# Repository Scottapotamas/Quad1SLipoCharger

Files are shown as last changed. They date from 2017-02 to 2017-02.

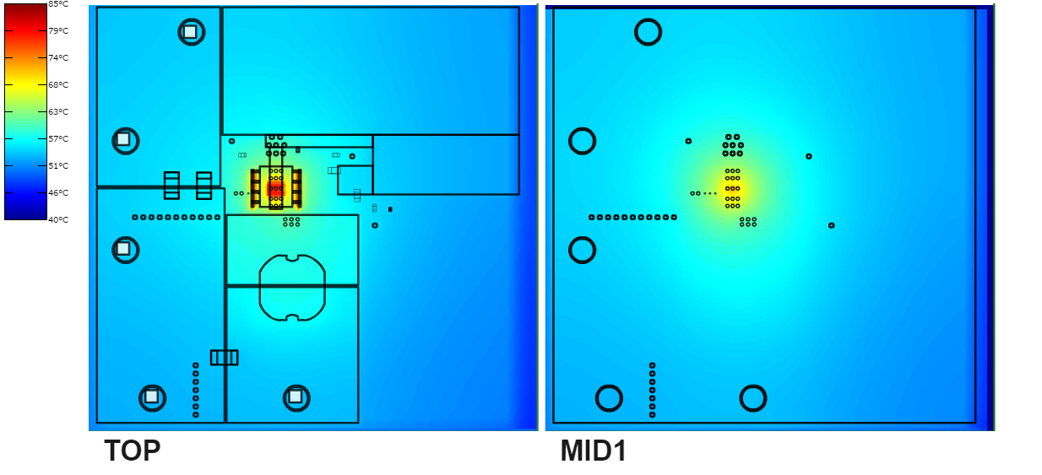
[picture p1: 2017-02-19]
Regulator Notes/Thermal 1.PNG

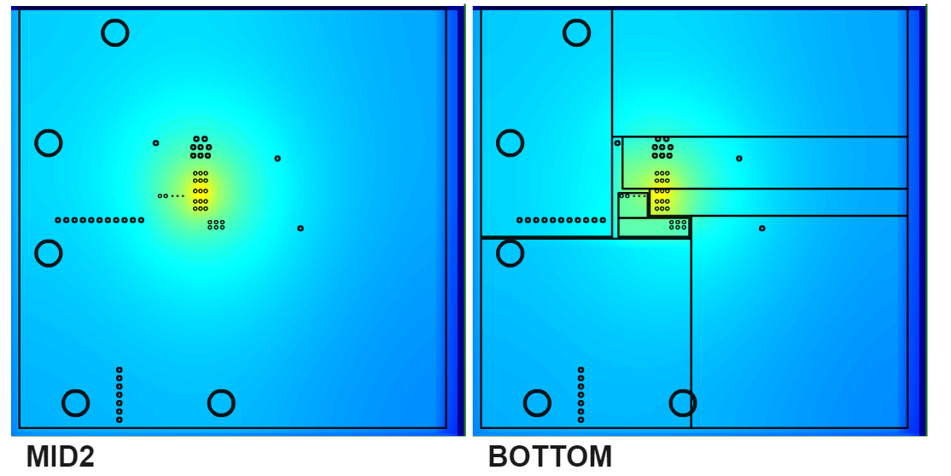
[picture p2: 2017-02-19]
Regulator Notes/Thermal 2.PNG

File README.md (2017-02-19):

# Quad1SLipoCharger
Charges up to 4 1S lipo batteries, independantly. Settable 300, 500 or 800mA charge current per battery.

# Version 2.0
Version 2.0 was the first variant that uses the STC08 IC for charging, as it offers better performance and programmable current limits which the older MAX charging IC didn't on V1.

A few of these V2 boards were made as a test, and performed very well charging 4 batteries in the field for micro brushed quads. 

The biggest issue has been the physical connectors to the batteries, given the multitude of competing battery connectors used on brushed aircraft. V2.0 used JST-PH and then adaptor cables I made up, but this doesn't suit the fully range as easily as hoped.

That said, two of these prototype boards have charged over 100 batteries with no issues, and charging/regulation seems safe, stable and reliable.

# Version 2.1

Having tested V2 in person some changes were made which are represented in V2.1, mainly increased thermal considerations, removal of some status leds, and simplification of the layout. 

Connectors were changed to be compatible with the smaller 1S batteries found on TinyWhoop/RTF planes, and rotated to allow for direct connections to the board.

The board was also shrunk, and the XT60 footprint corrected based on discoveries relating to incorrect datasheets used for V2.0 footprint design.

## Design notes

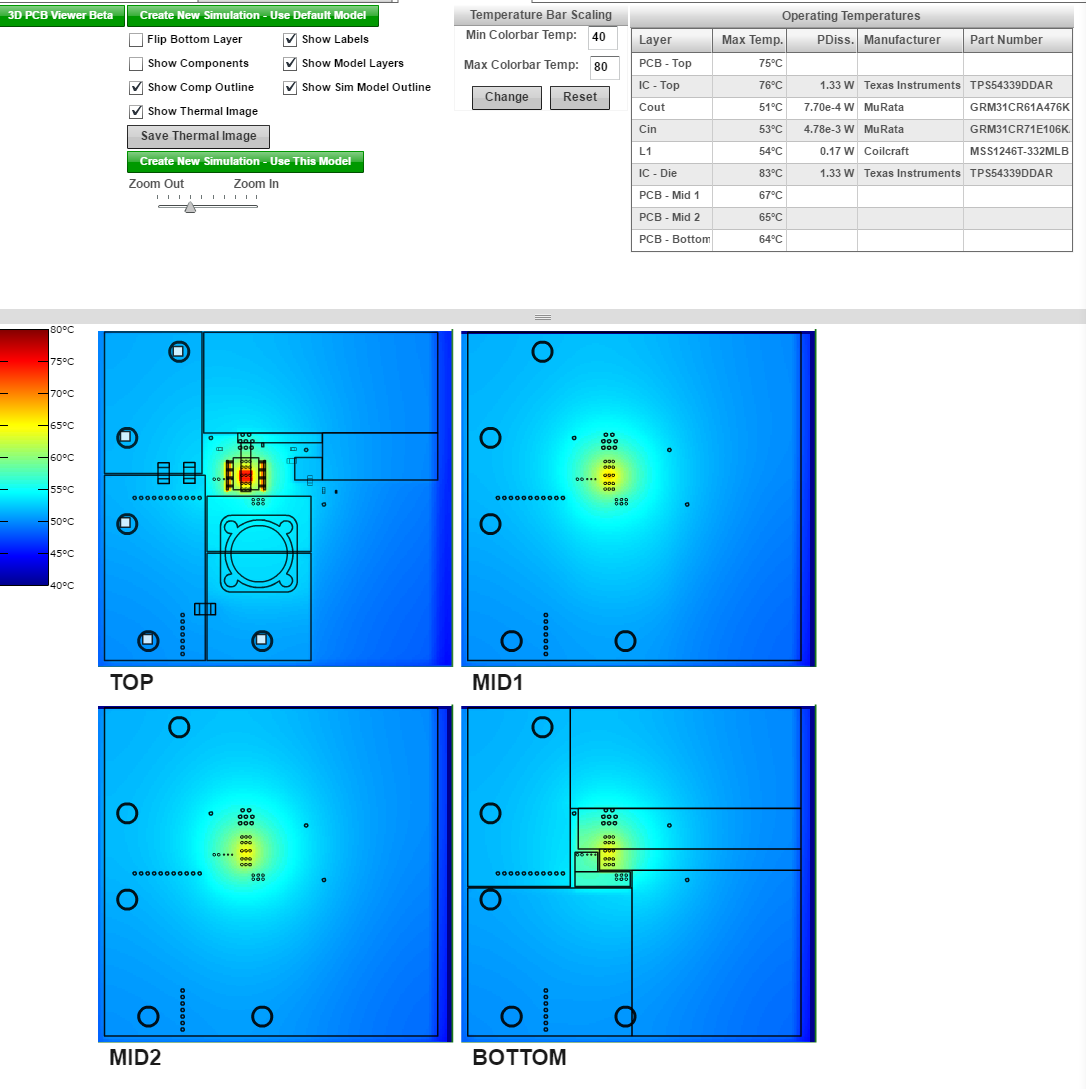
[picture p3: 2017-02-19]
Regulator Notes/Thermal 3S .PNG

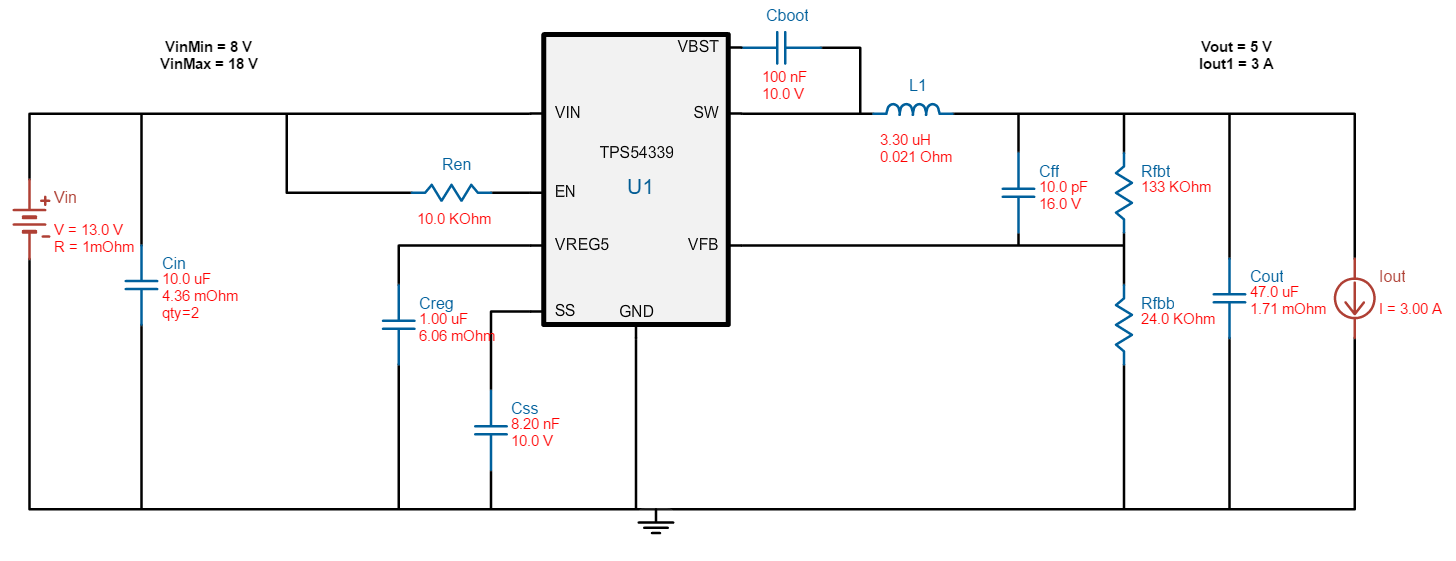
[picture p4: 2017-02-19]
Regulator Notes/PSU Circuit.PNG

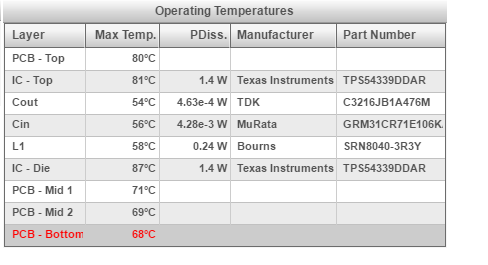
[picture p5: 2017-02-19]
Regulator Notes/Thermal Vals.PNG

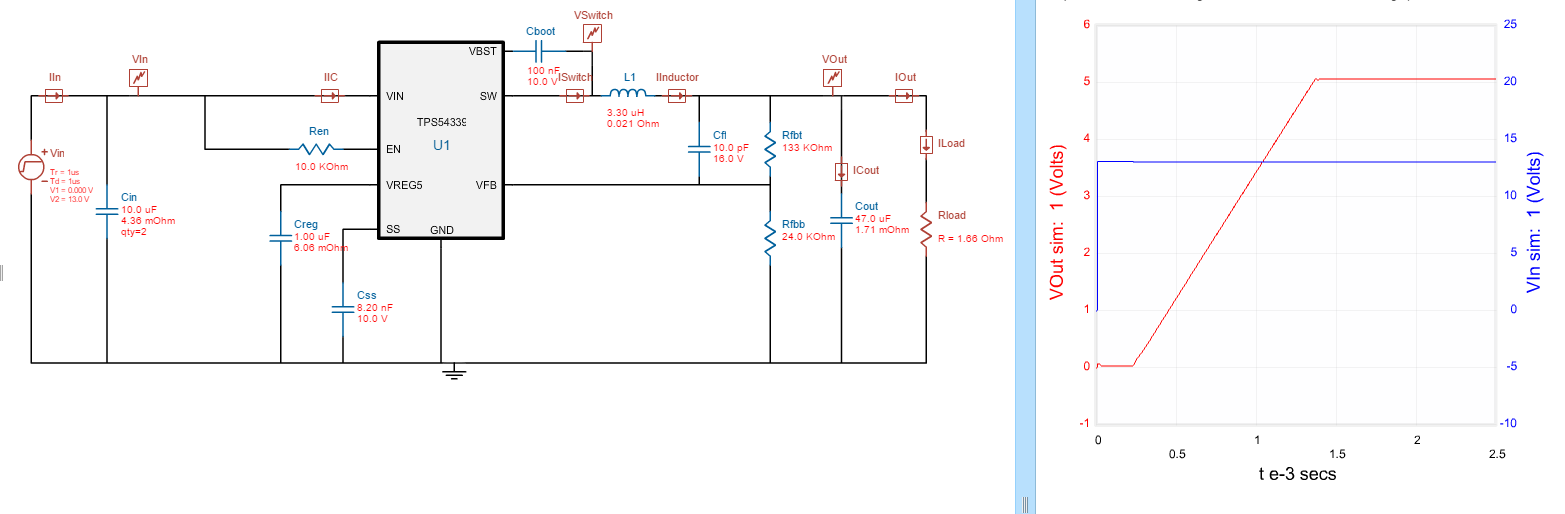
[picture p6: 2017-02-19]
Regulator Notes/PSU Sim.PNG

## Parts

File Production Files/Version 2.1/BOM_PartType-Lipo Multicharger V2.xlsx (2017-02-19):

Comment | Designator | Description | LibRef | Quantity | Note | Example
XT60PT |  | Amass PCB Mount XT60 Connector | CMP-ys0k18bgy9431xxyemrn-2 | 1 | If can't source easily I will solder myself | https://www.aliexpress.com/item/1-5-10-20-Pairs-Amass-XT60PT-3-5mm-Banana-Connector-Plug-Male-Female-Gold-plated/32706595068.html
Molex 53047-0210 | B1, B2, B3, B4 | 1.25mm Pitch PicoBlade™ Wire-to-Board Header, Vertical, 2 Circuits. | CMP-5075997b4c378fb2-1 | 4 | DO NOT PLACE, INCLUDE IN BAG
0603 100nF | C1 | AVX 0603 100nF 0603YC104K4Z2A | CMP-955451-2 | 1
0603 10pF | C2 | Multilayer Ceramic Capacitors MLCC - SMD/SMT 50volts 10pF 5% C0G | CMP-3554890-2 | 1
1210 10uF | C3, C4 | CAP CER 10UF 25V 10% X5R 1210 | CMP-127194-2 | 2
0603 1uF | C5, C8 | CAP CER 1UF 10V Y5V 0603 | CMP-126001-2 | 2
0603 10nF | C6 | CAP CER 10000PF 25V 10% X7R 0603 | CMP-171279-2 | 1
1210 47uF | C7, C17 | 1210 47 uF 10 V ±10% Tolerance X5R SMT Multilayer Ceramic Capacitor | CMP-cdd204dbeb8b1215-2 | 2
0603 4.7uF X5R | C9, C10, C11, C12, C13, C14, C15, C16 | Cap Ceramic 4.7uF 10V X5R 10% SMD 0603 85C | CMP-9133140-3 | 8
SMB 3A 40V | D1 | DIODE SCHOTTKY 100V 3A SMB | CMP-816754-2 | 1
SMAJ30CAHE3/5A | D2 | Transient Voltage Suppressor, 6.40 to 231 V, 30 V Stand-off Voltage, Bi-Directional, -55 to 155 degC, 2-pin DO-214AC | CMP-16576639-3 | 1 |  | https://www.aliexpress.com/item/Free-Shipping-Electronics-SMAJ30CAHE3-5A-TVS-BIDIR-400W-30V-5-SMA-SMAJ30CAHE3-SMAJ30-30C-20pcs/32433853051.html
0603 Red | POWER | Red 1.6 x 0.8 x 0.8 mm 130° Water Clear 10 mcd 2.1 V SMT LED | CMP-1544853-3 | 1
0603 Green | D4, D6, D8, D10 | Green 1.6 x 0.8 x 0.8 mm 130° Water Clear 6 mcd 2.1 V SMT LED | CMP-1544853-3 | 5
IHLP2525EZER3R3M01 | L1 | Surface Mount Power Inductor, IHLP-2525EZ-01 Series, 3.3 H, 20%, Shielded, 0.0209 ohm, 8 A | CMP-55fd9e7d09658a3a-1 | 1 |  | https://www.aliexpress.com/item/Free-shipping-5pcs-lot-IHLP2525CZER3R3M01-IHLP2525-SMD-original-Product/32518321538.html
0603 10k | R1 | RES SMD 10K OHM 0.1% 1/10W 0603 | CMP-1863099-2 | 1
0603 133k 1% | R3 | Thick Film Resistors - SMD 0603 133Kohms 1% Tol | CMP-3663980-2 | 1
0603 24k 1% | R4 | Thick Film Resistors - SMD 0603 24Kohms 5% Tol | CMP-3679912-2 | 1
0603 1k | R5, R5, R7, R17, R19 | 0603 Panasonic ERJ3EKF1001V 1kOhm, 5% Tol | CMP-3654795-5 | 5
0R 0402 | R9, R11, R21, R23 | Bridge resistor 0ohm 0402 Labelled on board as 0.5 | CMP-15792799-5 | 4
Bridge 0402 | R9, R10, R11, R12, R21, R22, R23, R24 | Bridge resistor 0ohm 0402 labelled on board as 0.3. | CMP-15792799-5 | DNP | DO NOT PLACE
0603 2k | R13, R15, R25, R27 | RES SMD 2K OHM 5% 1/10W 0603 | CMP-1877180-2 | 4
0603 3.33k | R14, R16, R26, R28 | Thick Film Resistors - SMD 0603 3.3Kohms 5% Tol | CMP-3656259-2 | 4
STMicroelectronics STBC08PMR | U1, U2, U3, U4 | IC BATT CHRGR LI-ION 4.2V 800MA DFN6 | CMP-facc33d44885250b-1 | 4
Texas Instruments TPS54339DDA | U5 | 4.5V to 23V Input, 3A Synchronous Step-Down Converter with D-CAP2 Mode 8-SO PowerPAD -40 to 85 | CMP-82774aeb049e5db0-1 | 1

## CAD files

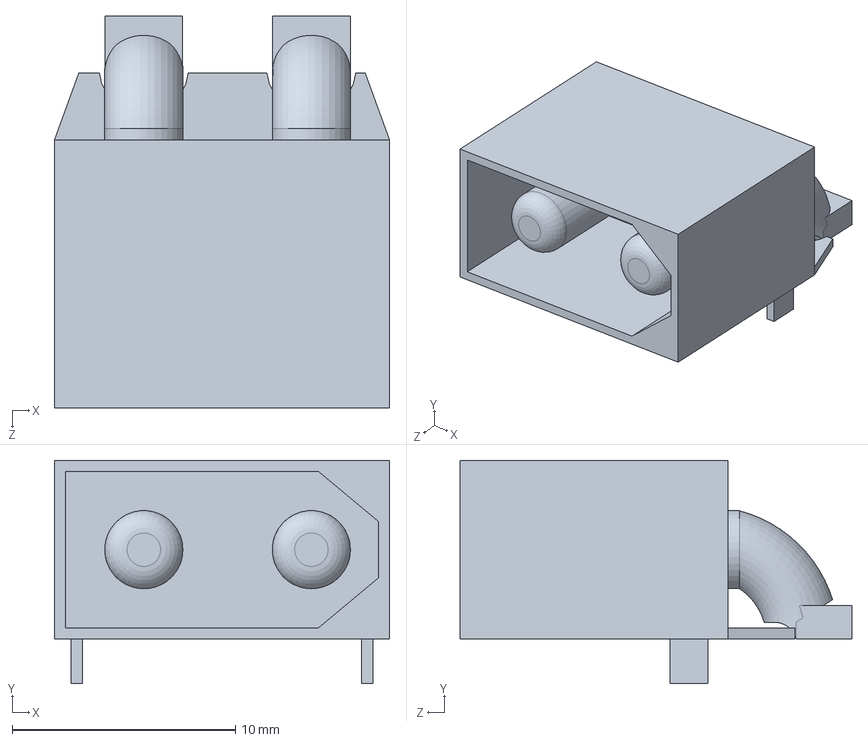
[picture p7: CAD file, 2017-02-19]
CAD/xt60pt.SLDPRT
15.0 x 10.0 x 17.5 mm

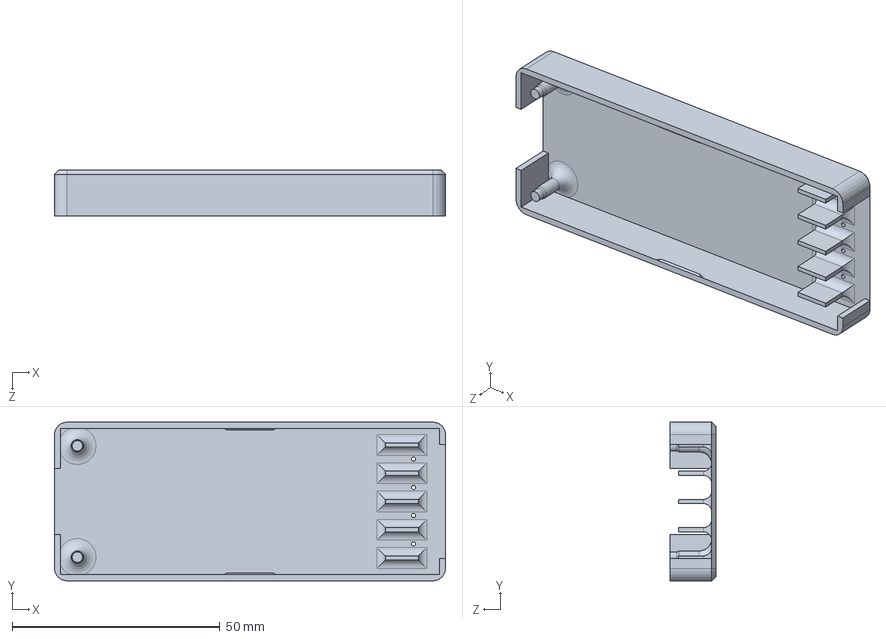
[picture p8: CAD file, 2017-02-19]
CAD/Charger housing.SLDPRT
94.1 x 38.2 x 11.0 mm

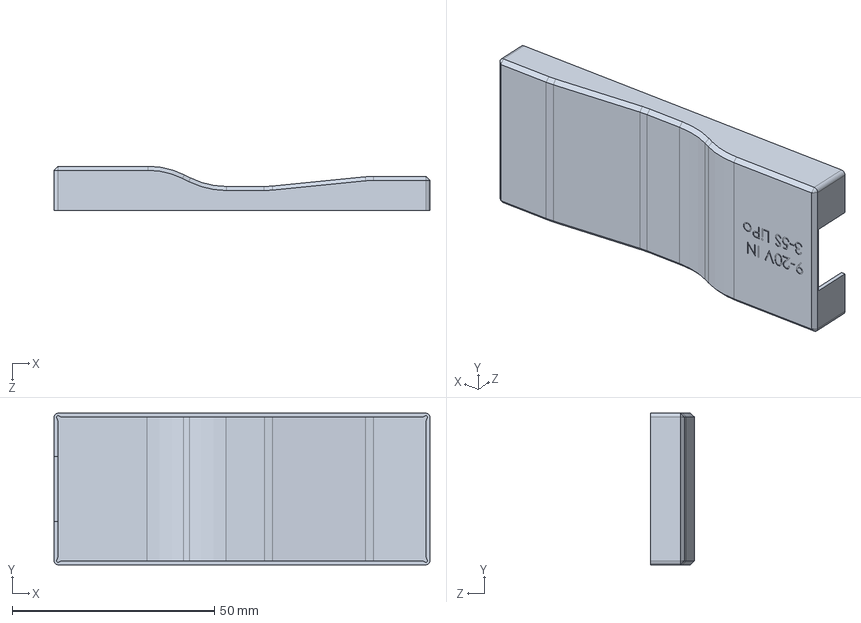
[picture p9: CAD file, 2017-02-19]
CAD/Charger housing V2.SLDPRT
93.0 x 37.5 x 11.0 mm

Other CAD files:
CAD/xt60pt v2.STEP
CAD/Charger housing V1.SLDPRT

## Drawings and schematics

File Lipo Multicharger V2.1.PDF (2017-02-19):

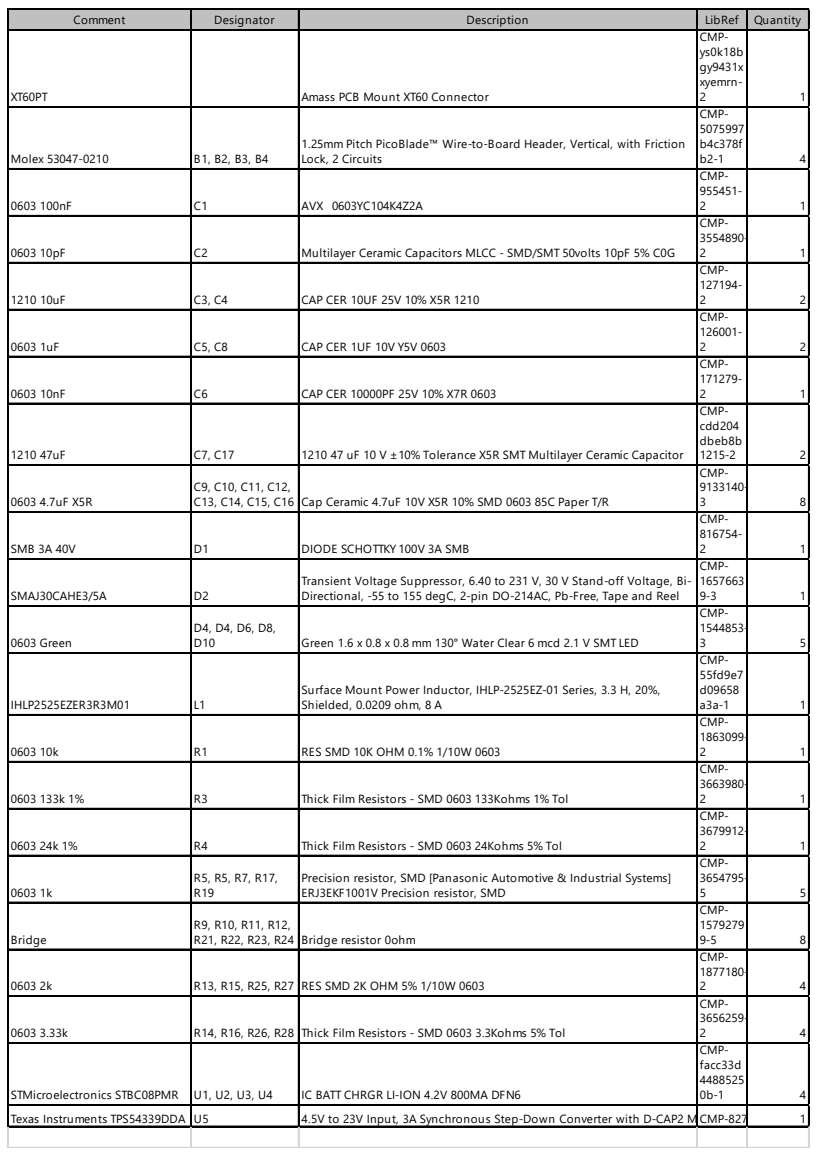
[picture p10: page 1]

Comment | Designator | Description | LibRef | Quantity

XT60PT | | Amass PCB Mount XT60 Connector | CMP-ys0k18b gy9431x xyemrn-2 | 1

Molex 53047-0210 | B1, B2, B3, B4 | 1.25mm Pitch PicoBlade™ Wire-to-Board Header, Vertical, with Friction Lock, 2 Circuits | CMP-5075997 b4c378f b2-1 | 4

0603 100nF | C1 | AVX 0603YC104K4Z2A | CMP-955451-2 | 1

0603 10pF | C2 | Multilayer Ceramic Capacitors MLCC - SMD/SMT 50volts 10pF 5% C0G | CMP-3554890-2 | 1

1210 10uF | C3, C4 | CAP CER 10UF 25V 10% X5R 1210 | CMP-127194-2 | 2

0603 1uF | C5, C8 | CAP CER 1UF 10V Y5V 0603 | CMP-126001-2 | 2

0603 10nF | C6 | CAP CER 10000PF 25V 10% X7R 0603 | CMP-171279-2 | 1

1210 47uF | C7, C17 | 1210 47 uF 10 V ±10% Tolerance X5R SMT Multilayer Ceramic Capacitor | CMP-cdd204 dbeb8b 1215-2 | 2

0603 4.7uF X5R | C9, C10, C11, C12, C13, C14, C15, C16 | Cap Ceramic 4.7uF 10V X5R 10% SMD 0603 85C Paper T/R | CMP-9133140-3 | 8

SMB 3A 40V | D1 | DIODE SCHOTTKY 100V 3A SMB | CMP-816754-2 | 1

SMAJ30CAHE3/5A | D2 | Transient Voltage Suppressor, 6.40 to 231 V, 30 V Stand-off Voltage, Bi-Directional, -55 to 155 degC, 2-pin DO-214AC, Pb-Free, Tape and Reel | CMP-1657663 9-3 | 1

0603 Green | D4, D4, D6, D8, D10 | Green 1.6 x 0.8 x 0.8 mm 130° Water Clear 6 mcd 2.1 V SMT LED | CMP-1544853-3 | 5

IHLP2525EZER3R3M01 | L1 | Surface Mount Power Inductor, IHLP-2525EZ-01 Series, 3.3 H, 20%, Shielded, 0.0209 ohm, 8 A | CMP-55fd9e7 d09658 a3a-1 | 1

0603 10k | R1 | RES SMD 10K OHM 0.1% 1/10W 0603 | CMP-1863099-2 | 1

0603 133k 1% | R3 | Thick Film Resistors - SMD 0603 133Kohms 1% Tol | CMP-3663980-2 | 1

0603 24k 1% | R4 | Thick Film Resistors - SMD 0603 24Kohms 5% Tol | CMP-3679912-2 | 1

0603 1k | R5, R5, R7, R17, R19 | Precision resistor, SMD [Panasonic Automotive & Industrial Systems] ERJ3EKF1001V Precision resistor, SMD | CMP-3654795-5 | 5

Bridge | R9, R10, R11, R12, R21, R22, R23, R24 | Bridge resistor 0ohm | CMP-1579279 9-5 | 8

0603 2k | R13, R15, R25, R27 | RES SMD 2K OHM 5% 1/10W 0603 | CMP-1877180-2 | 4

0603 3.33k | R14, R16, R26, R28 | Thick Film Resistors - SMD 0603 3.3Kohms 5% Tol | CMP-3656259-2 | 4

STMicroelectronics STBC08PMR | U1, U2, U3, U4 | IC BATT CHRGR LI-ION 4.2V 800MA DFN6 | CMP-facc33d 0b-1 | 4

Texas Instruments TPS54339DDA | U5 | 4.5V to 23V Input, 3A Synchronous Step-Down Converter with D-CAP2 MCMP -82774a | | 1

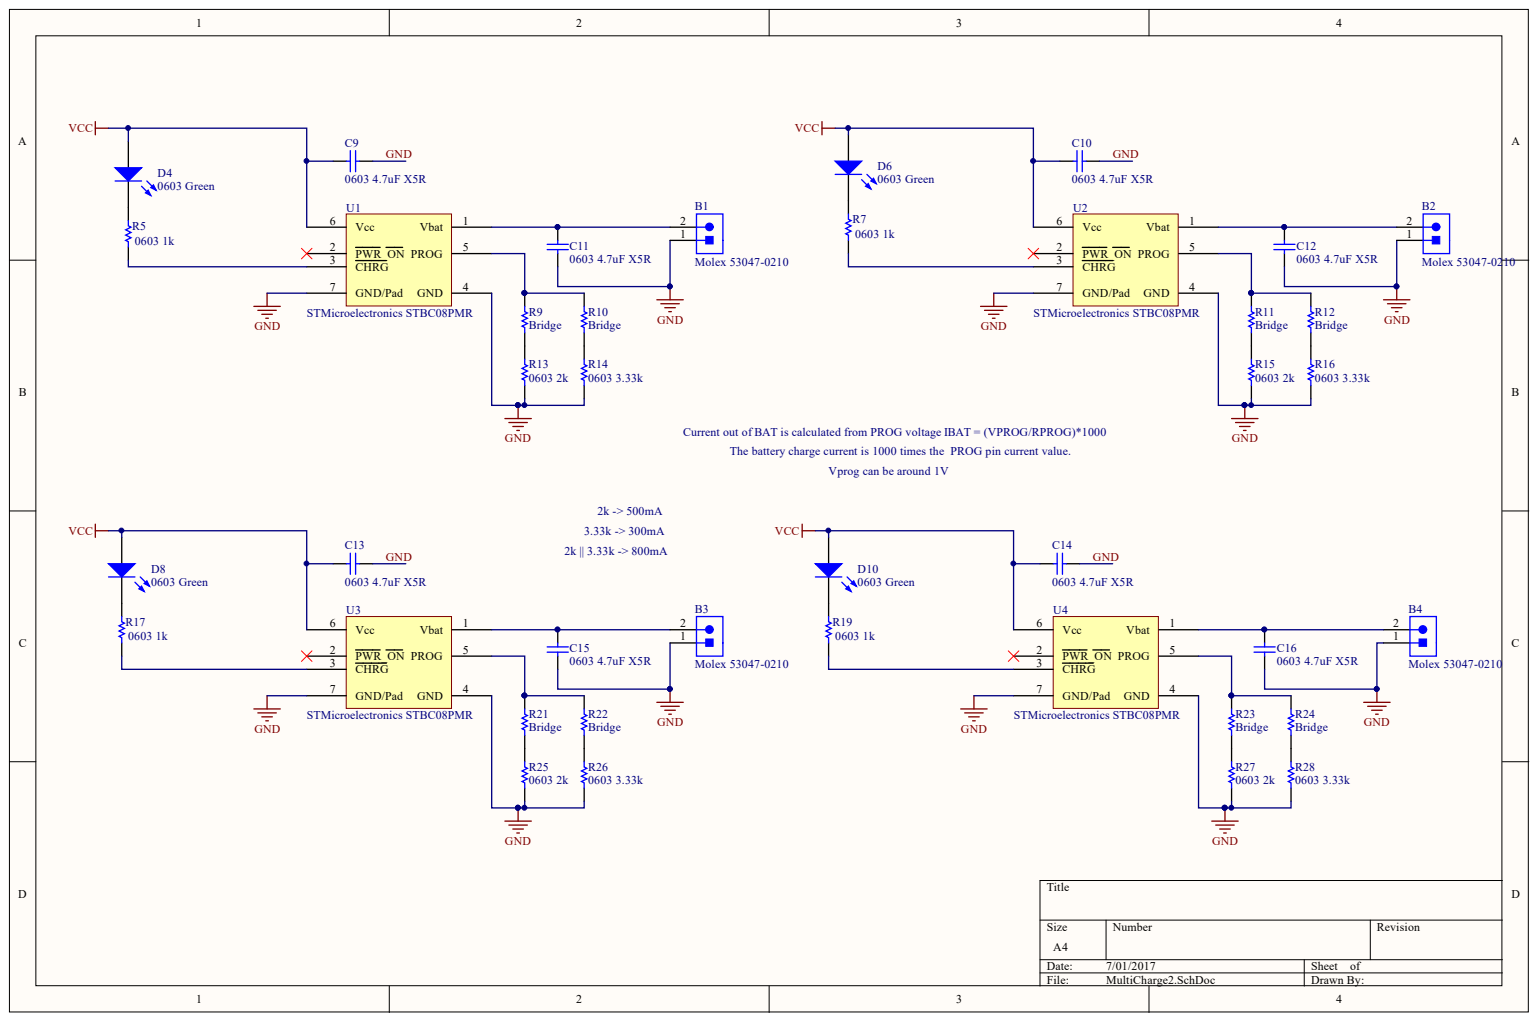
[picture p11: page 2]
Sheet o; ics STBC0; 3 Green; lex 5

D Current out of BAT is calculated from PROG voltage IBAT = (VPROG/RPROG)*1000 The battery charge current is 1000 times the PROG pin current value.

g can be aro

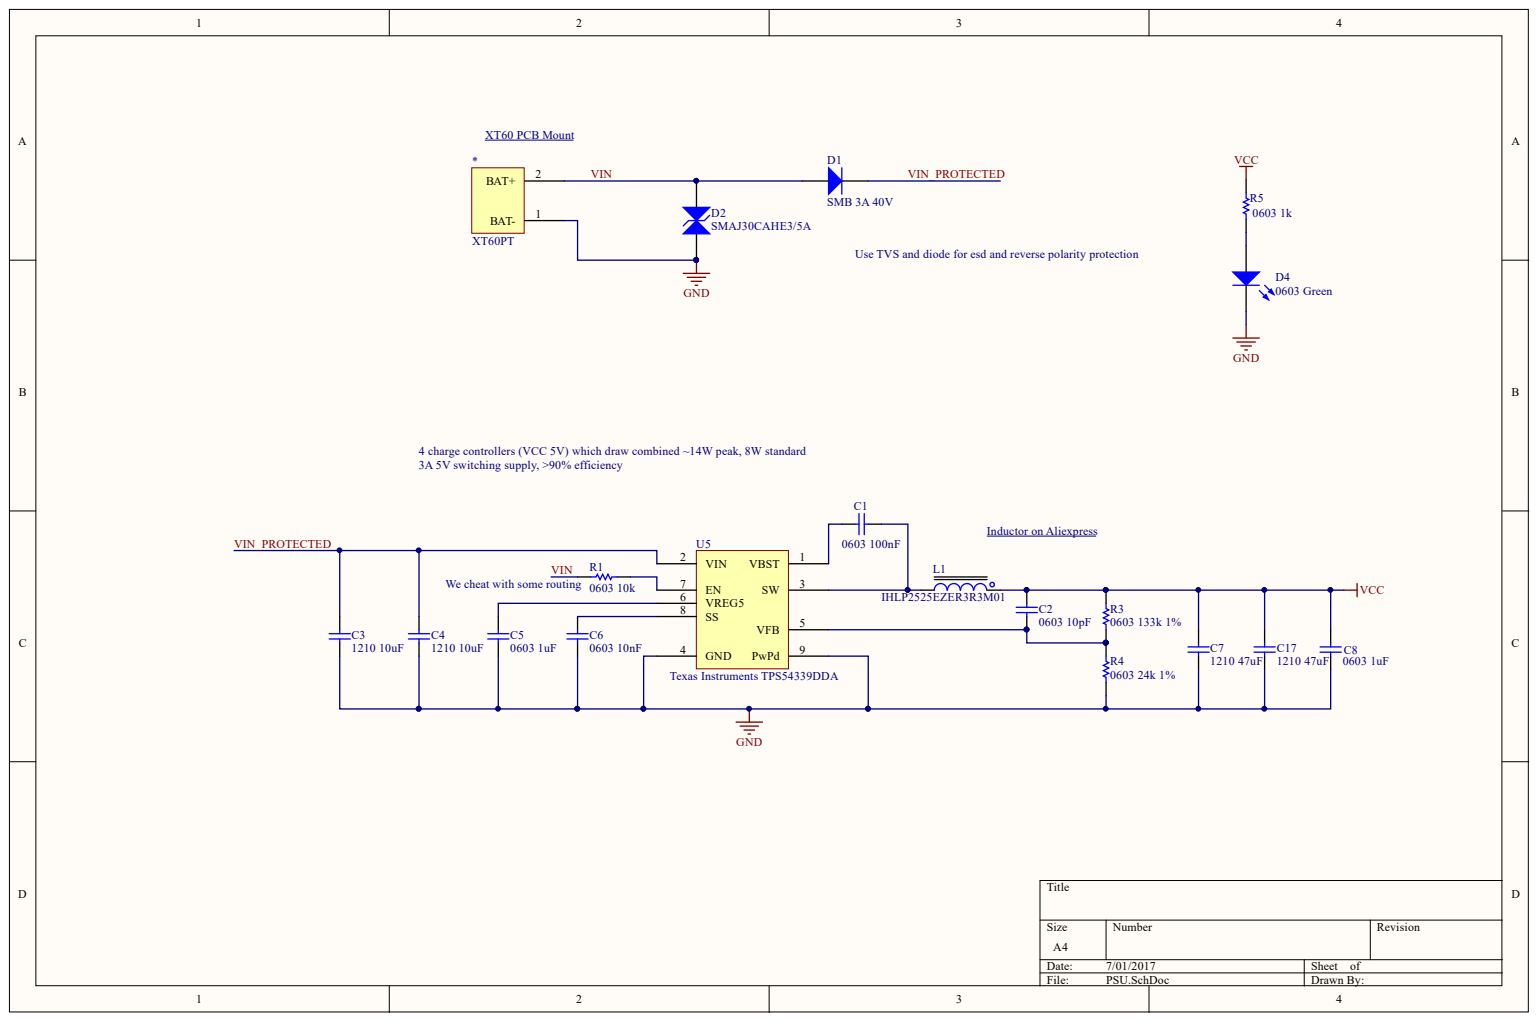
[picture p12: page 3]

Use TVS and diode for esd and reverse polarity protection

4 charge controllers (VCC 5V) which draw combined ~14W peak, 8W standard
3A 5V switching supply, >90% efficiency

We cheat with some routing

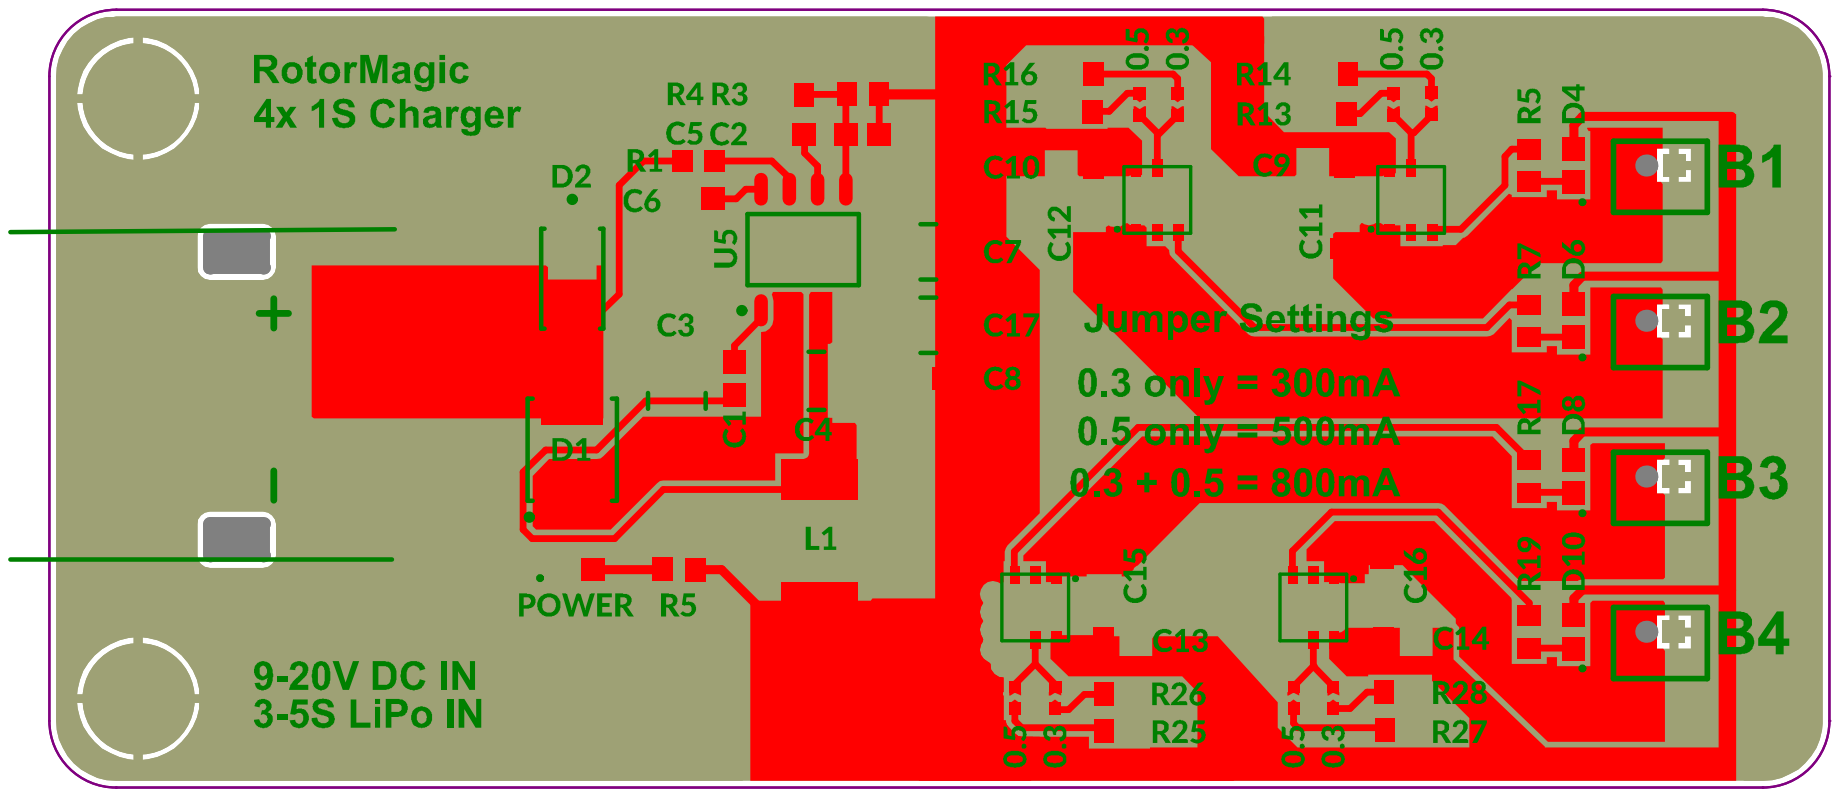
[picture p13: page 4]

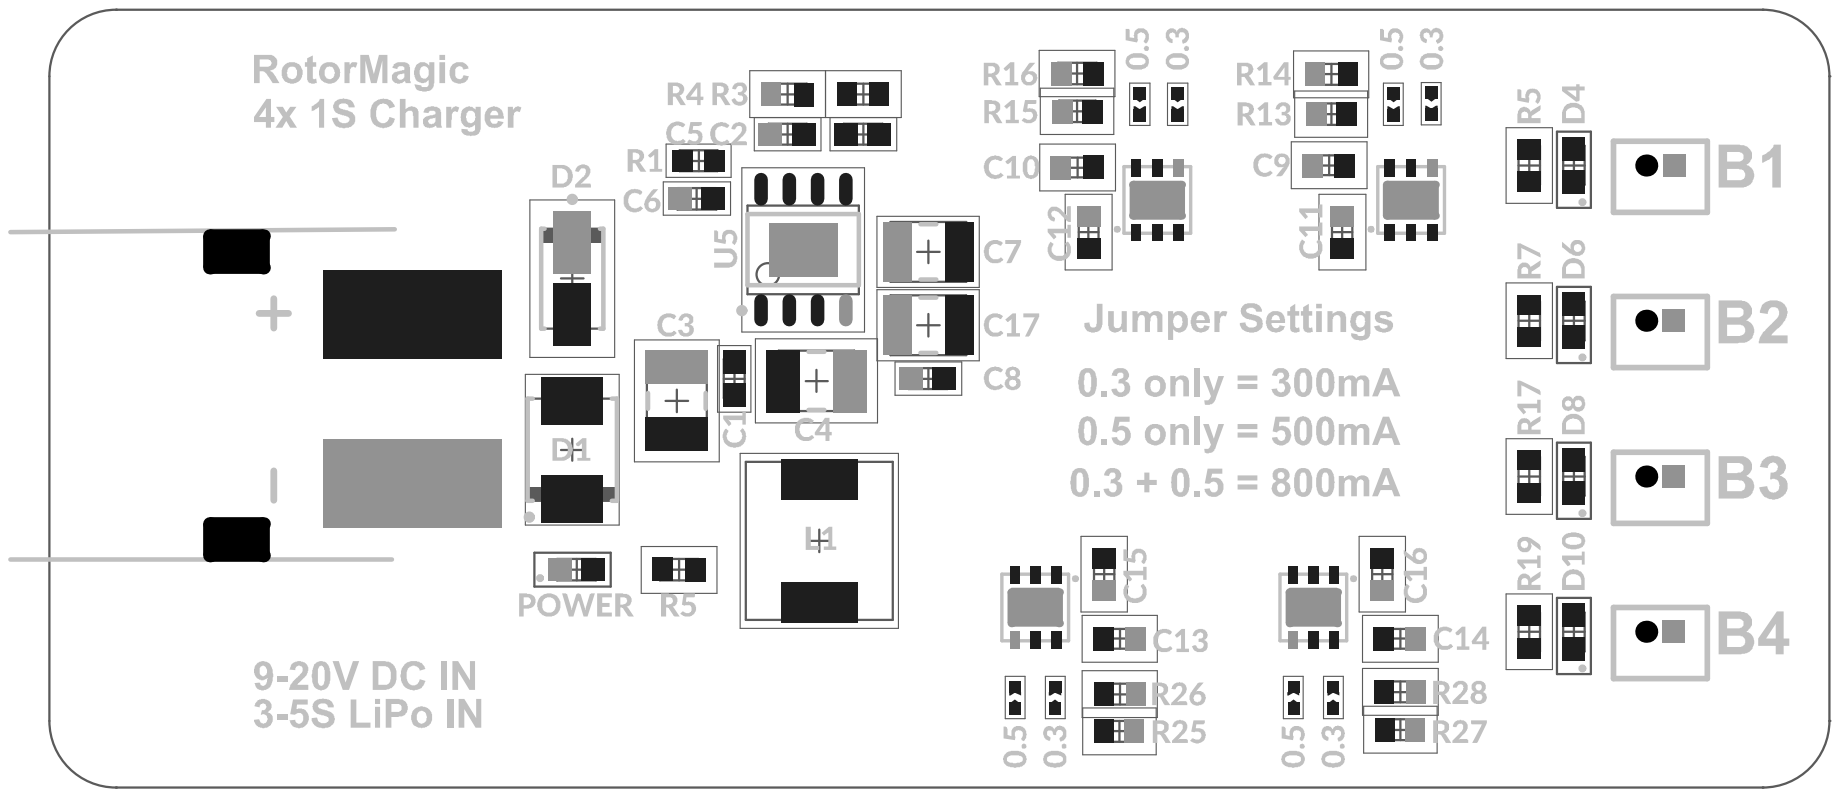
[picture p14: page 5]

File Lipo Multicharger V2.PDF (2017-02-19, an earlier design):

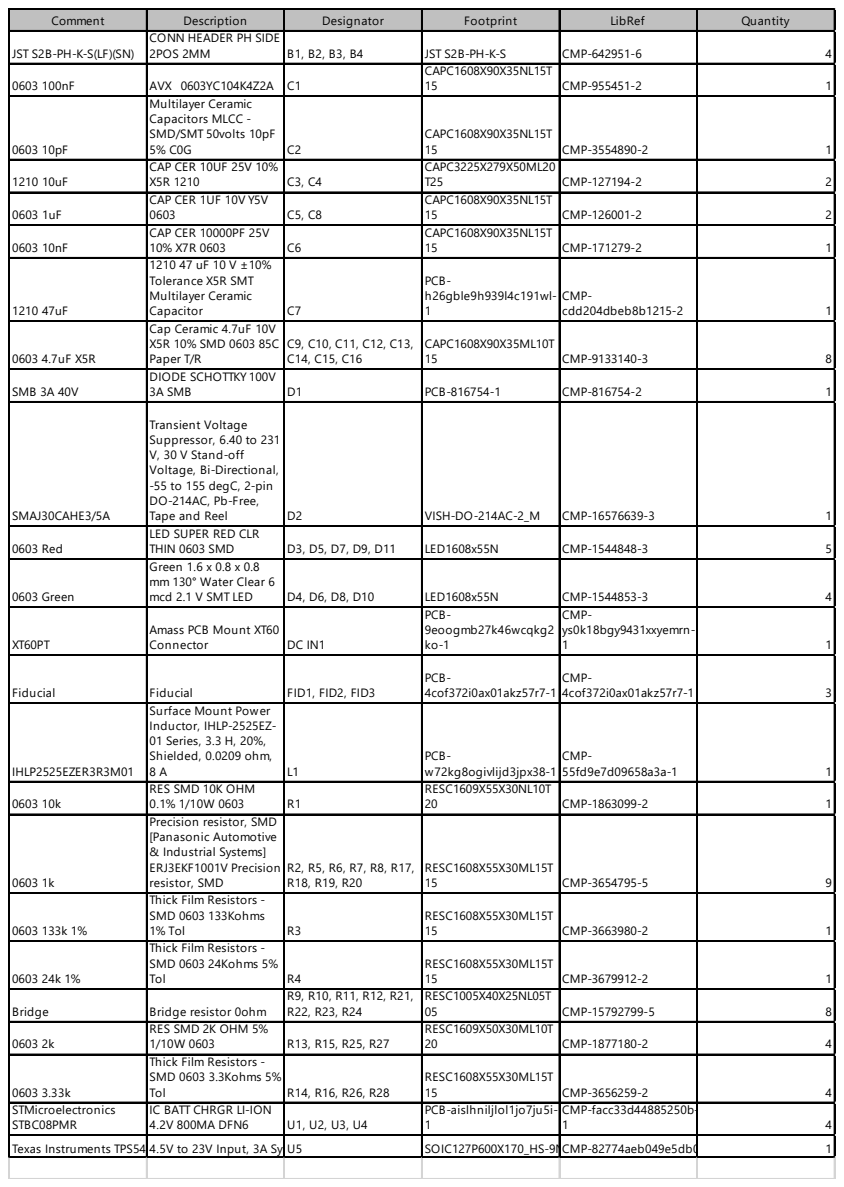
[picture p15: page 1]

Comment | Description | Designator | Footprint | LibRef | Quantity

JST S2B-PH-K-S(LF)(SN) | CONN HEADER PH SIDE 2POS 2MM | B1, B2, B3, B4 | JST S2B-PH-K-S | CMP-642951-6 | 4

0603 100nF | AVX 0603YC104K4Z2A | C1 | CAPC1608X90X35NL15T 15 | CMP-955451-2 | 1

0603 10pF | Multilayer Ceramic Capacitors MLCC -SMD/SMT 50volts 10pF 5% C0G | C2 | CAPC1608X90X35NL15T 15 | CMP-3554890-2 | 1

1210 10uF | CAP CER 10UF 25V 10% X5R 1210 | C3, C4 | CAPC3225X279X50ML20 T25 | CMP-127194-2 | 2

0603 1uF | CAP CER 1UF 10V Y5V 0603 | C5, C8 | CAPC1608X90X35NL15T 15 | CMP-126001-2 | 2

0603 10nF | CAP CER 10000PF 25V 10% X7R 0603 | C6 | CAPC1608X90X35NL15T 15 | CMP-171279-2 | 1

1210 47uF | 1210 47 uF 10 V ±10% Tolerance X5R SMT Multilayer Ceramic Capacitor | C7 | PCB-h26gble9h939l4c191wl-1 | CMP-cdd204dbeb8b1215-2 | 1

0603 4.7uF X5R | Cap Ceramic 4.7uF 10V X5R 10% SMD 0603 85C Paper T/R | C9, C10, C11, C12, C13, C14, C15, C16 | CAPC1608X90X35ML10T 15 | CMP-9133140-3 | 8

SMB 3A 40V | DIODE SCHOTTKY 100V 3A SMB | D1 | PCB-816754-1 | CMP-816754-2 | 1

SMAJ30CAHE3/5A | Transient Voltage Suppressor, 6.40 to 231 V, 30 V Stand-off Voltage, Bi-Directional, -55 to 155 degC, 2-pin DO-214AC, Pb-Free, Tape and Reel | D2 | VISH-DO-214AC-2_M | CMP-16576639-3 | 1

0603 Red | LED SUPER RED CLR THIN 0603 SMD | D3, D5, D7, D9, D11 | LED1608x55N | CMP-1544848-3 | 5

0603 Green | Green 1.6 x 0.8 x 0.8 mm 130° Water Clear 6 mcd 2.1 V SMT LED | D4, D6, D8, D10 | LED1608x55N | CMP-1544853-3 | 4

XT60PT | Amass PCB Mount XT60 Connector | DC IN1 | PCB-9eoogmb27k46wcqkg2 ko-1 | CMP-ys0k18bgy9431xxyemrn-1 | 1

Fiducial | Fiducial | FID1, FID2, FID3 | PCB-4cof372i0ax01akz57r7-1 | CMP-4cof372i0ax01akz57r7-1 | 3

IHLP2525EZER3R3M01 | Surface Mount Power Inductor, IHLP-2525EZ-01 Series, 3.3 H, 20%, Shielded, 0.0209 ohm, 8 A | L1 | PCB-w72kg8ogivlijd3jpx38-1 | CMP-55fd9e7d09658a3a-1 | 1

0603 10k | RES SMD 10K OHM 0.1% 1/10W 0603 | R1 | RESC1609X55X30NL10T 20 | CMP-1863099-2 | 1

0603 1k | Precision resistor, SMD [Panasonic Automotive & Industrial Systems] ERJ3EKF1001V Precision resistor, SMD | R2, R5, R6, R7, R8, R17, R18, R19, R20 | RESC1608X55X30ML15T 15 | CMP-3654795-5 | 9

0603 133k 1% | Thick Film Resistors -SMD 0603 133Kohms 1% Tol | R3 | RESC1608X55X30ML15T 15 | CMP-3663980-2 | 1

0603 24k 1% | Thick Film Resistors -SMD 0603 24Kohms 5% Tol | R4 | RESC1608X55X30ML15T 15 | CMP-3679912-2 | 1

Bridge | Bridge resistor 0ohm | R9, R10, R11, R12, R21, R22, R23, R24 | RESC1005X40X25NL05T 05 | CMP-15792799-5 | 8

0603 2k | RES SMD 2K OHM 5% 1/10W 0603 | R13, R15, R25, R27 | RESC1609X50X30ML10T 20 | CMP-1877180-2 | 4

0603 3.33k | Thick Film Resistors -SMD 0603 3.3Kohms 5% Tol | R14, R16, R26, R28 | RESC1608X55X30ML15T 15 | CMP-3656259-2 | 4

STMicroelectronics STBC08PMR | IC BATT CHRGR LI-ION 4.2V 800MA DFN6 | U1, U2, U3, U4 | PCB-aislhniljlol1jo7ju5i- | CMP-facc33d44885250b-1 | 4

Texas Instruments TPS54339D 4.5V to 23V Input, 3A SynU5 | | | SOIC127P 600X 170_ H S-9NCM P-82774a eb049e 5d b0- | | 1

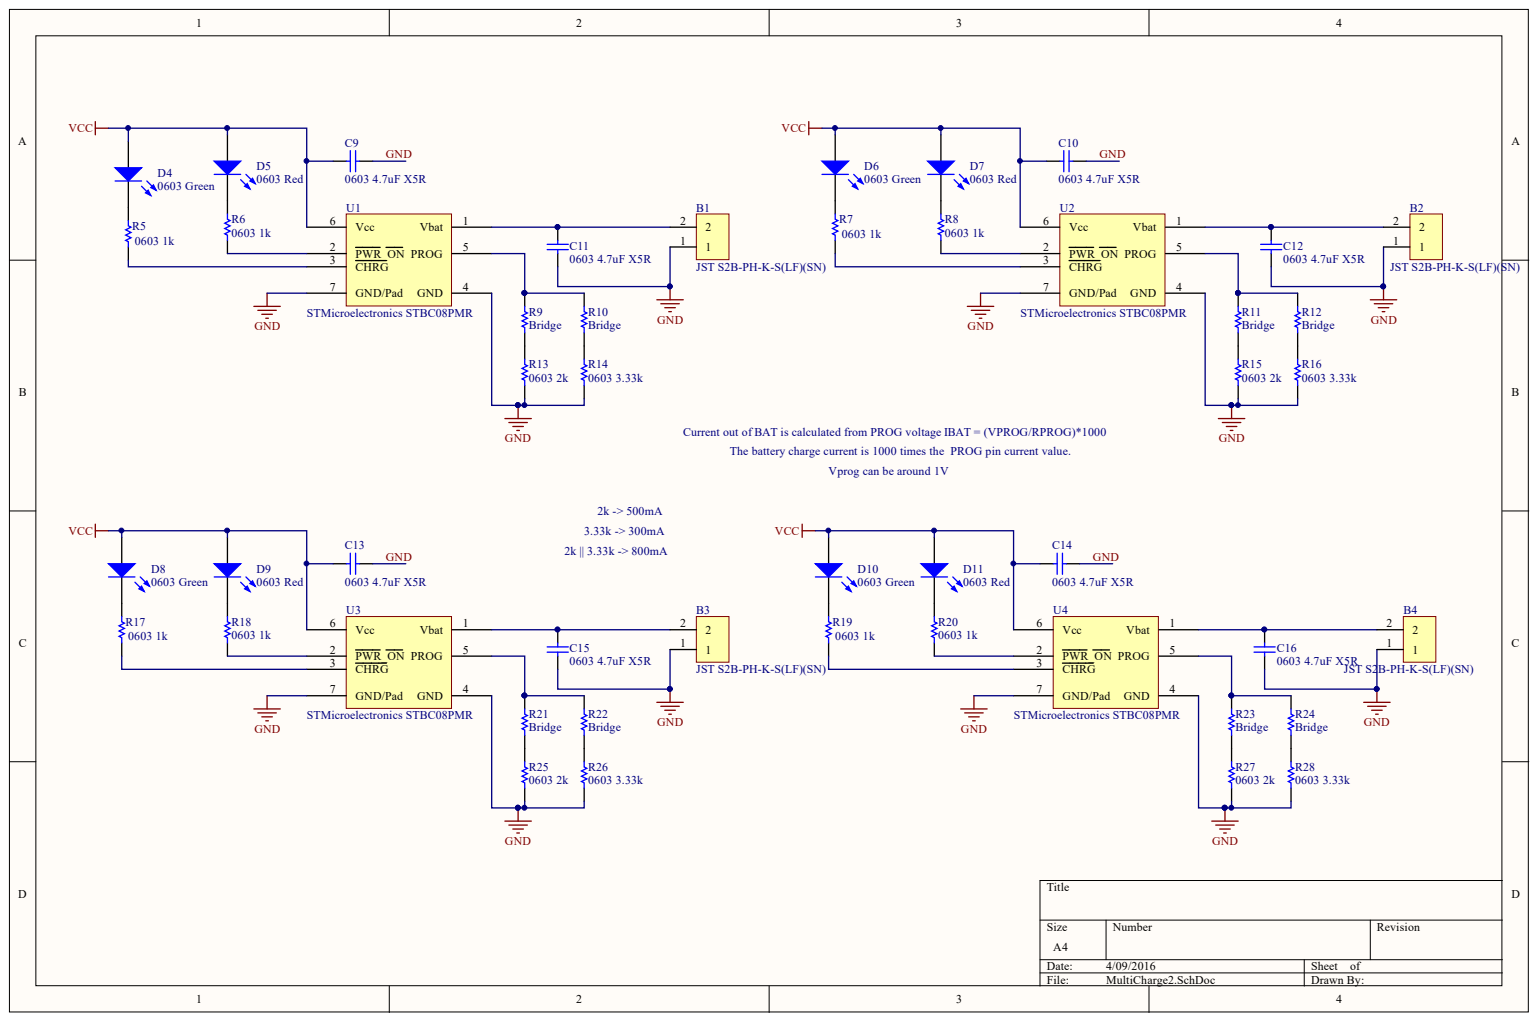
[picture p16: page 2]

JST S2B-PH-K-S(LF)(SN

D Current out of BAT is calculated from PROG voltage IBAT = (VPROG/RPROG)*1000 The battery charge current is 1000 times the PROG pin current value.

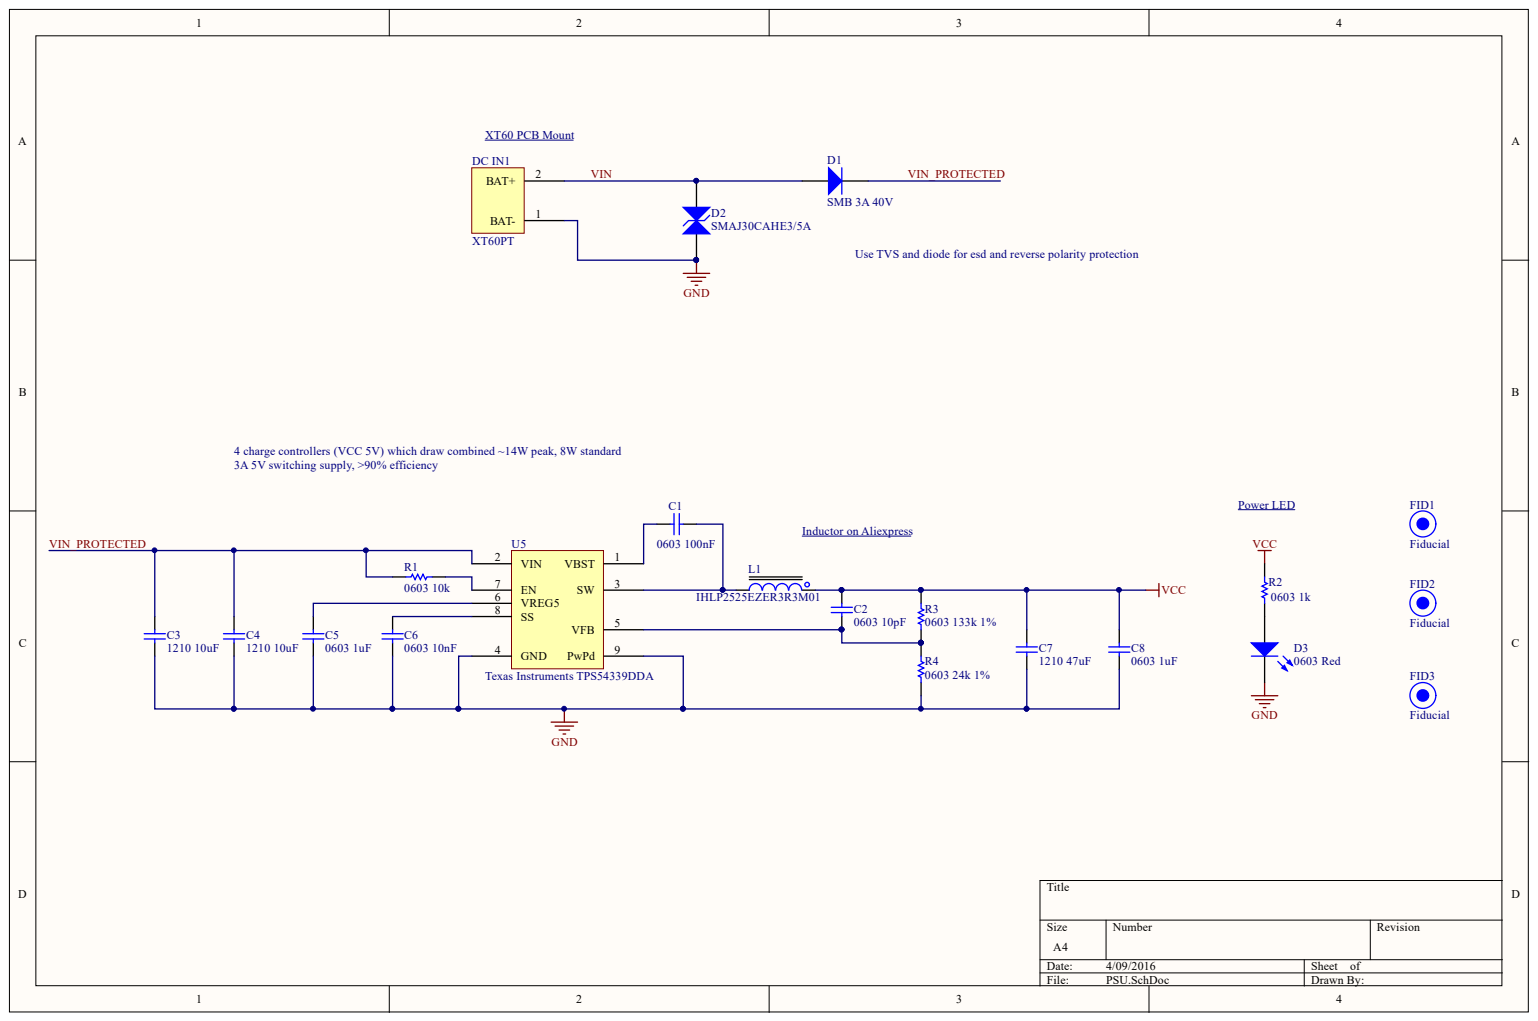
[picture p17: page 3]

Use TVS and diode for esd and reverse polarity protection

4 charge controllers (VCC 5V) which draw combined ~14W peak, 8W standard
3A 5V switching supply, >90% efficiency

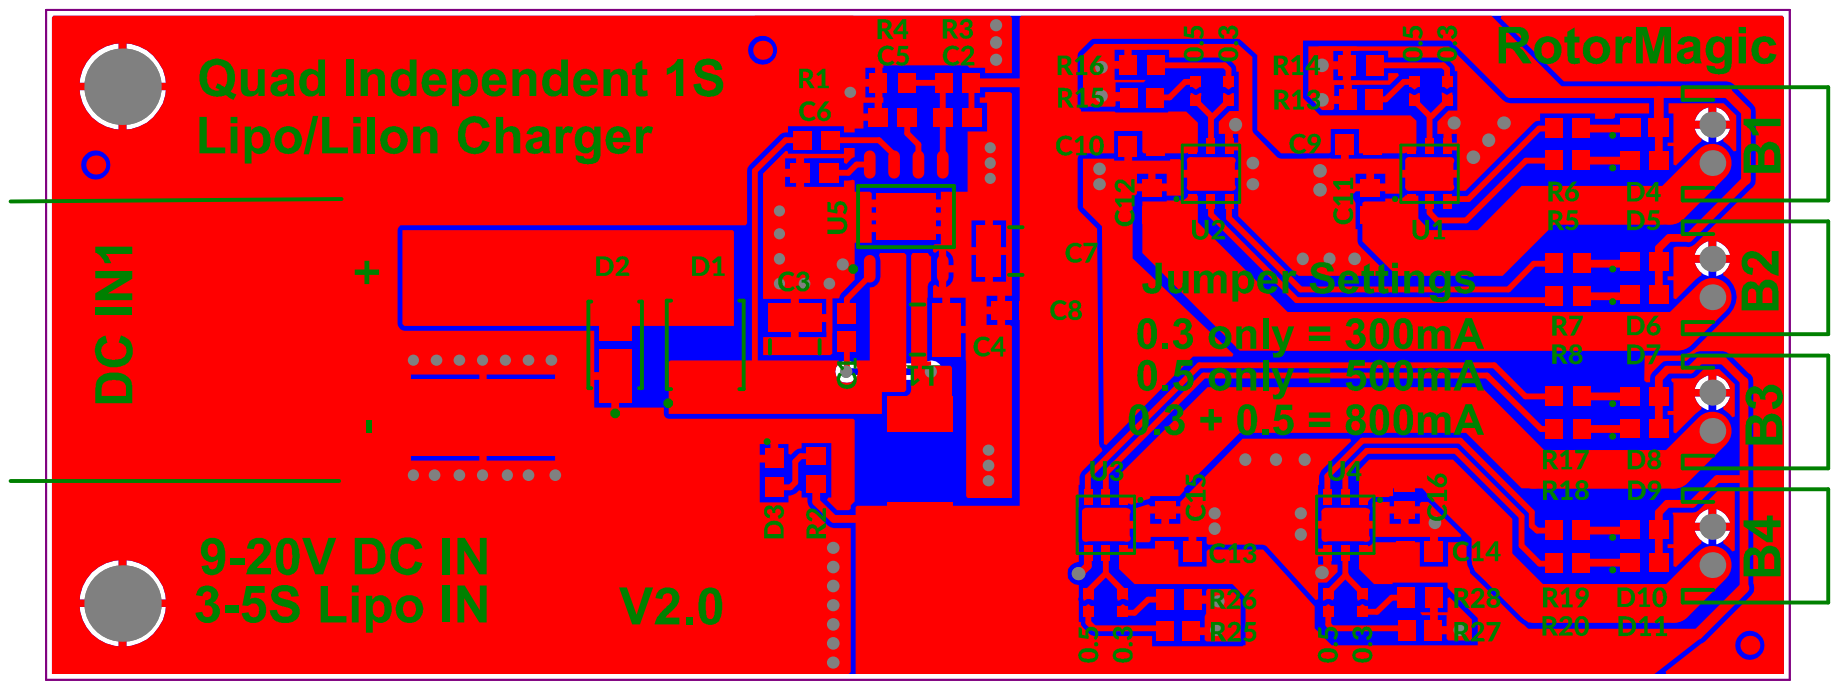
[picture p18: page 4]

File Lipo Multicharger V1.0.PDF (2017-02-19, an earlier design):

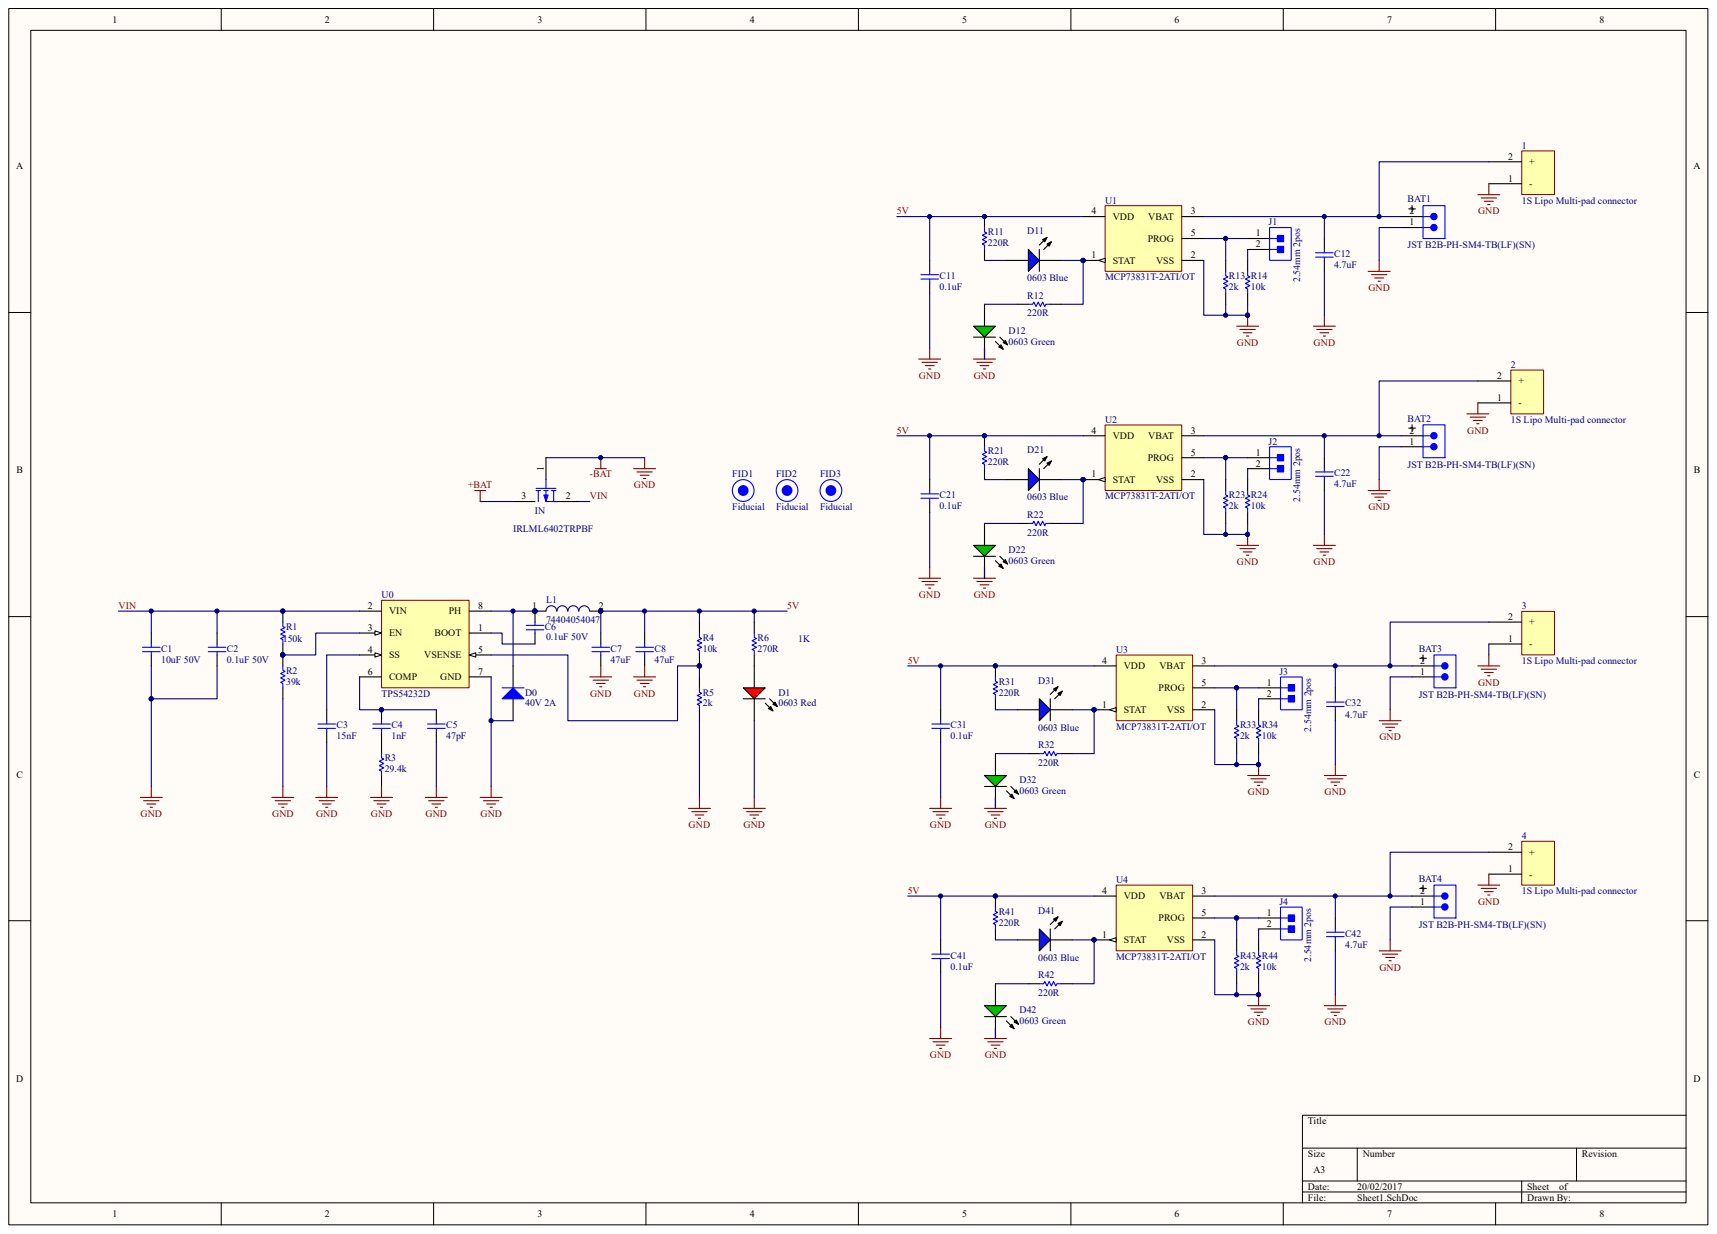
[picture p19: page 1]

JST B2B-PH-SM4-TB(LF)(SN)

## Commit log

2017-02-19 Added schematic and BOM
    [BOM_PartType-Lipo Multicharger V2.xlsx]
2017-02-19 Added gerbers for V2.0 (first board using this ST charge IC after the MAX attempt wasn't viable)
    [MultiChargerv2.GBL, MultiChargerv2.GBO, MultiChargerv2.GBP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]
2017-02-19 Gerbers, schematic added for version 2.1
    [BOM_PartType-Lipo Multicharger V2.xlsx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]
2017-02-19 Enclosure concept models added
    [Charger housing V1.SLDPRT, Charger housing V2.SLDPRT, Charger housing.SLDPRT]
2017-02-19 Regulator IC design notes from WeBench added
2017-02-19 AMASS XT60 SMD mount step files added
    [xt60pt v2.STEP, xt60pt.SLDPRT]
2017-02-19 Added older version 1.0 design based on MCP7383
    [PCB1.GBL, PCB1.GBO, PCB1.GBP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]
